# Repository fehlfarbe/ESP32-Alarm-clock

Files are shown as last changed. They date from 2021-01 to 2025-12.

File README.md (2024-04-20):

# ESP32 Alarm clock

This is an ESP32 based alarm clock that plays mp3 files from SD, webstreams or even FM radio.
You can configure multiple alarms and add new songs to your sd card with a simple webinterface.

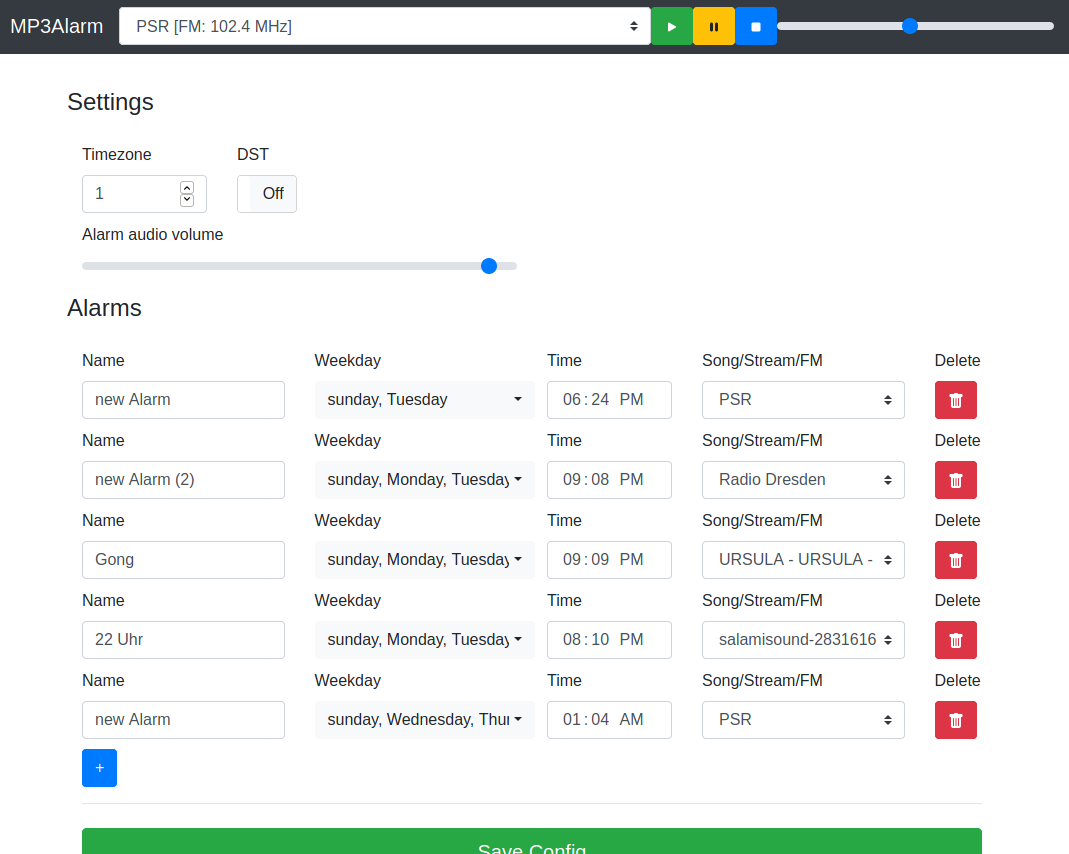
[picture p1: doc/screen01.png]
Screenshot of webinterface


Photos of the current PCB version (without assembled radio antenna connector J10):

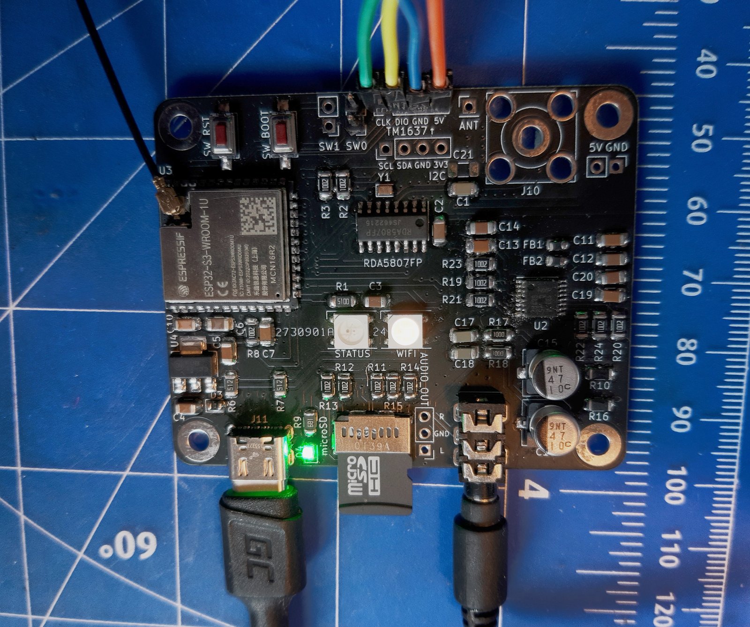
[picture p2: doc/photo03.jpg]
Photo of current PCB top

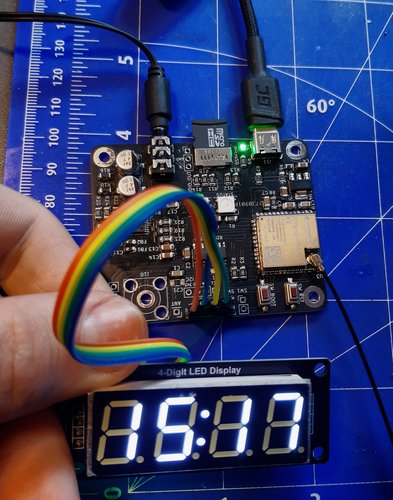
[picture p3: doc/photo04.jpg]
Photo of current PCB with digital clock display


## Features

- designed for ESP32 S3 microcontroller
- plays audio from different sources:
  - MP3/AAC from SD
  - webstreams via WiFi
  - FM radio via [RDA5807FP](https://opendevices.ru/wp-content/uploads/2015/10/RDA5807FP.pdf) module
- output via I2S to a stereo decoder like the [UDA1334A](https://learn.adafruit.com/adafruit-i2s-stereo-decoder-uda1334a).
- see current time on TM1637 4-Digit Digital LED display
- see current WiFi state with WS2812 RGB LED
- simple config and file upload via webinterface

## Hardware

The KiCAD project and gerber files are available at `hardware/pcb/`

### Schematic
schematic

### 2D Plot

#### Front
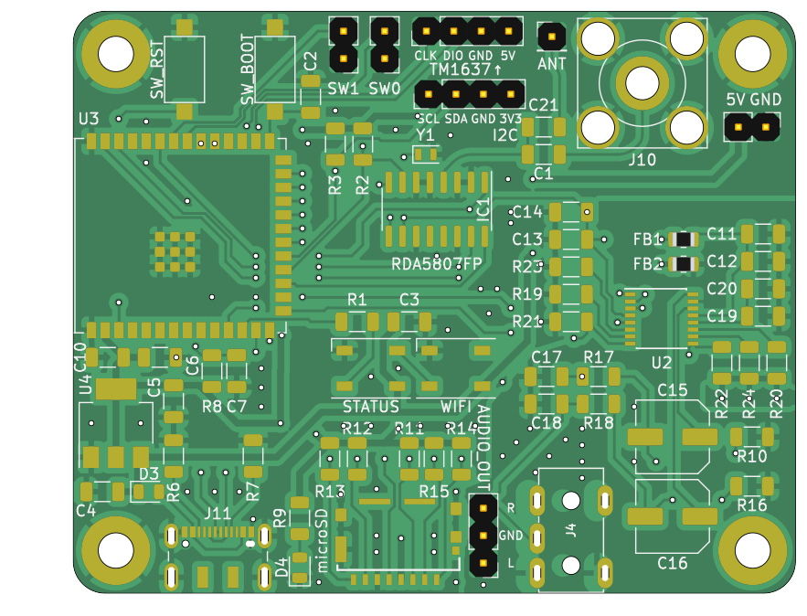
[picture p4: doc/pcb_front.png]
PCB front


#### Back
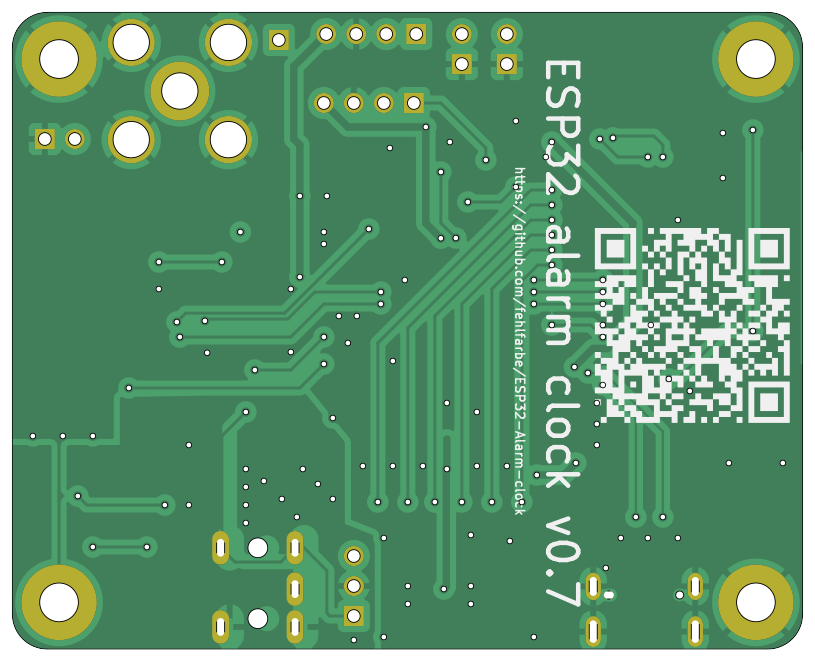
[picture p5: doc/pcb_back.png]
PCB back


### 3D Render

#### Front
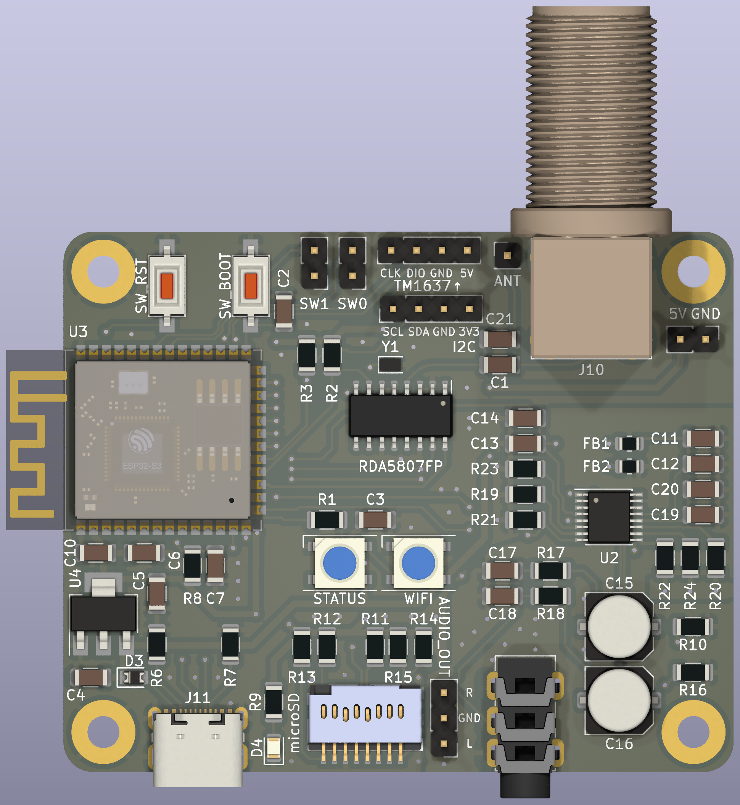
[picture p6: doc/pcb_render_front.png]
PCB front


#### Back
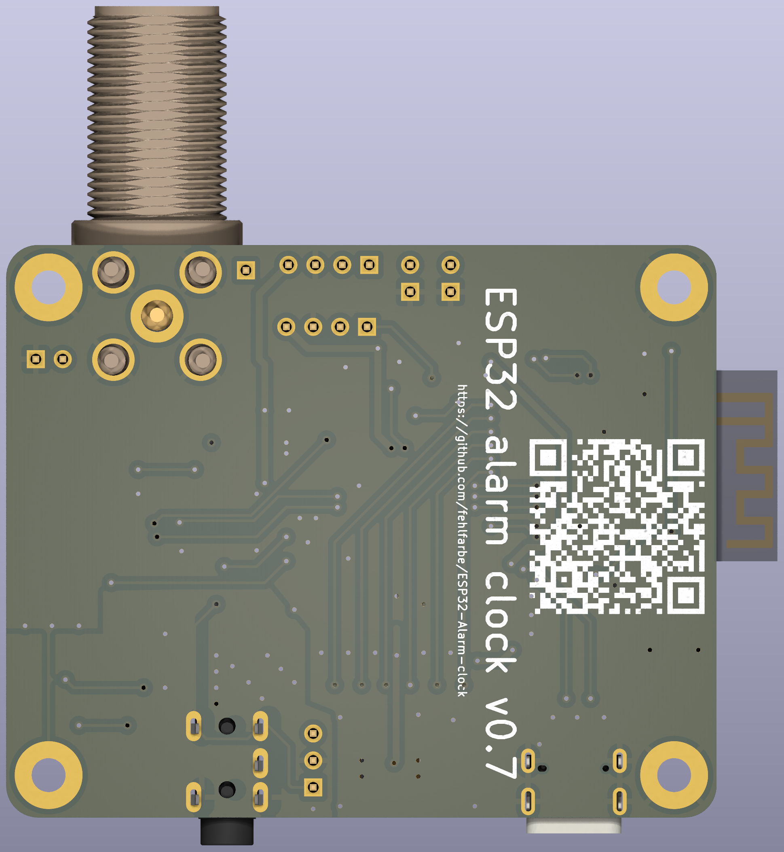
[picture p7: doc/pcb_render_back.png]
PCB back


### BOM

`hardware/pcb/export/BOM.xml`

## LED States

### Status LED

- red 1Hz blinking: An Error has occurred while mounting LITTLEFS
- red 0.5Hz blinking: Cannot mount SD card
- green Everything is fine :)

### WiFi LED

-  blue AccessPoint mode: Connect to the ESP's access point and configure your WiFi
-  red...green WiFi signal strength from bad to good

## Installation

Just clone the project and open it in platformIO. PIO will download all necessary libs. Connect the ESP32 on your USB port an click "Upload" in PIO. After this open a terminal in PIO and run `pio run -t uploadfs` to upload the webinterface to ESP32's flash.
The ESP32 will reboot and opens an accesspoint where you can connect to your WiFi. The clock is synced over the internet via NTP.

## ToDo

- [ ] Add alarm timeout (for webstreams, radio etc.)
- [ ] better web UI based on react
- [x] pictures of full assembled board
- [ ] complete BOM list

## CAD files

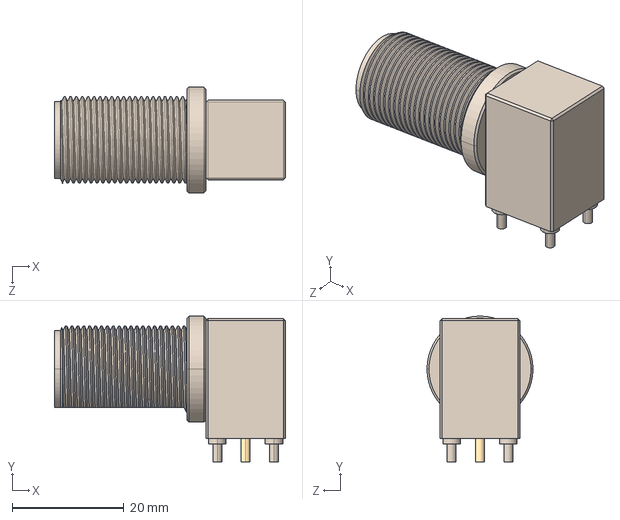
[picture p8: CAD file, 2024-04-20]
hardware/pcb/res/Amphenol RF 172363.STEP
41.4 x 26.1 x 19.0 mm

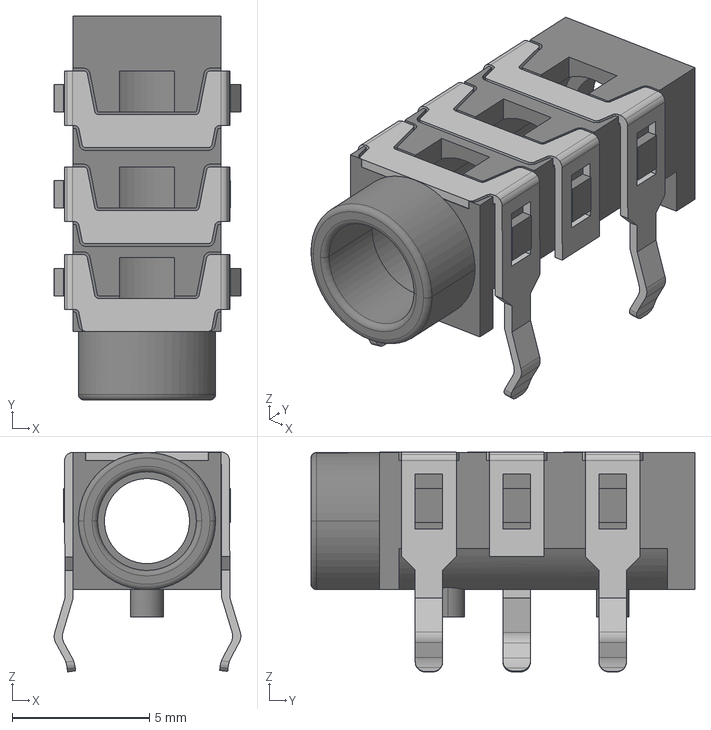
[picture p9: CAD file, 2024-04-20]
hardware/pcb/res/TRS Jack PJ-313.stp
6.81 x 14.0 x 8.02 mm

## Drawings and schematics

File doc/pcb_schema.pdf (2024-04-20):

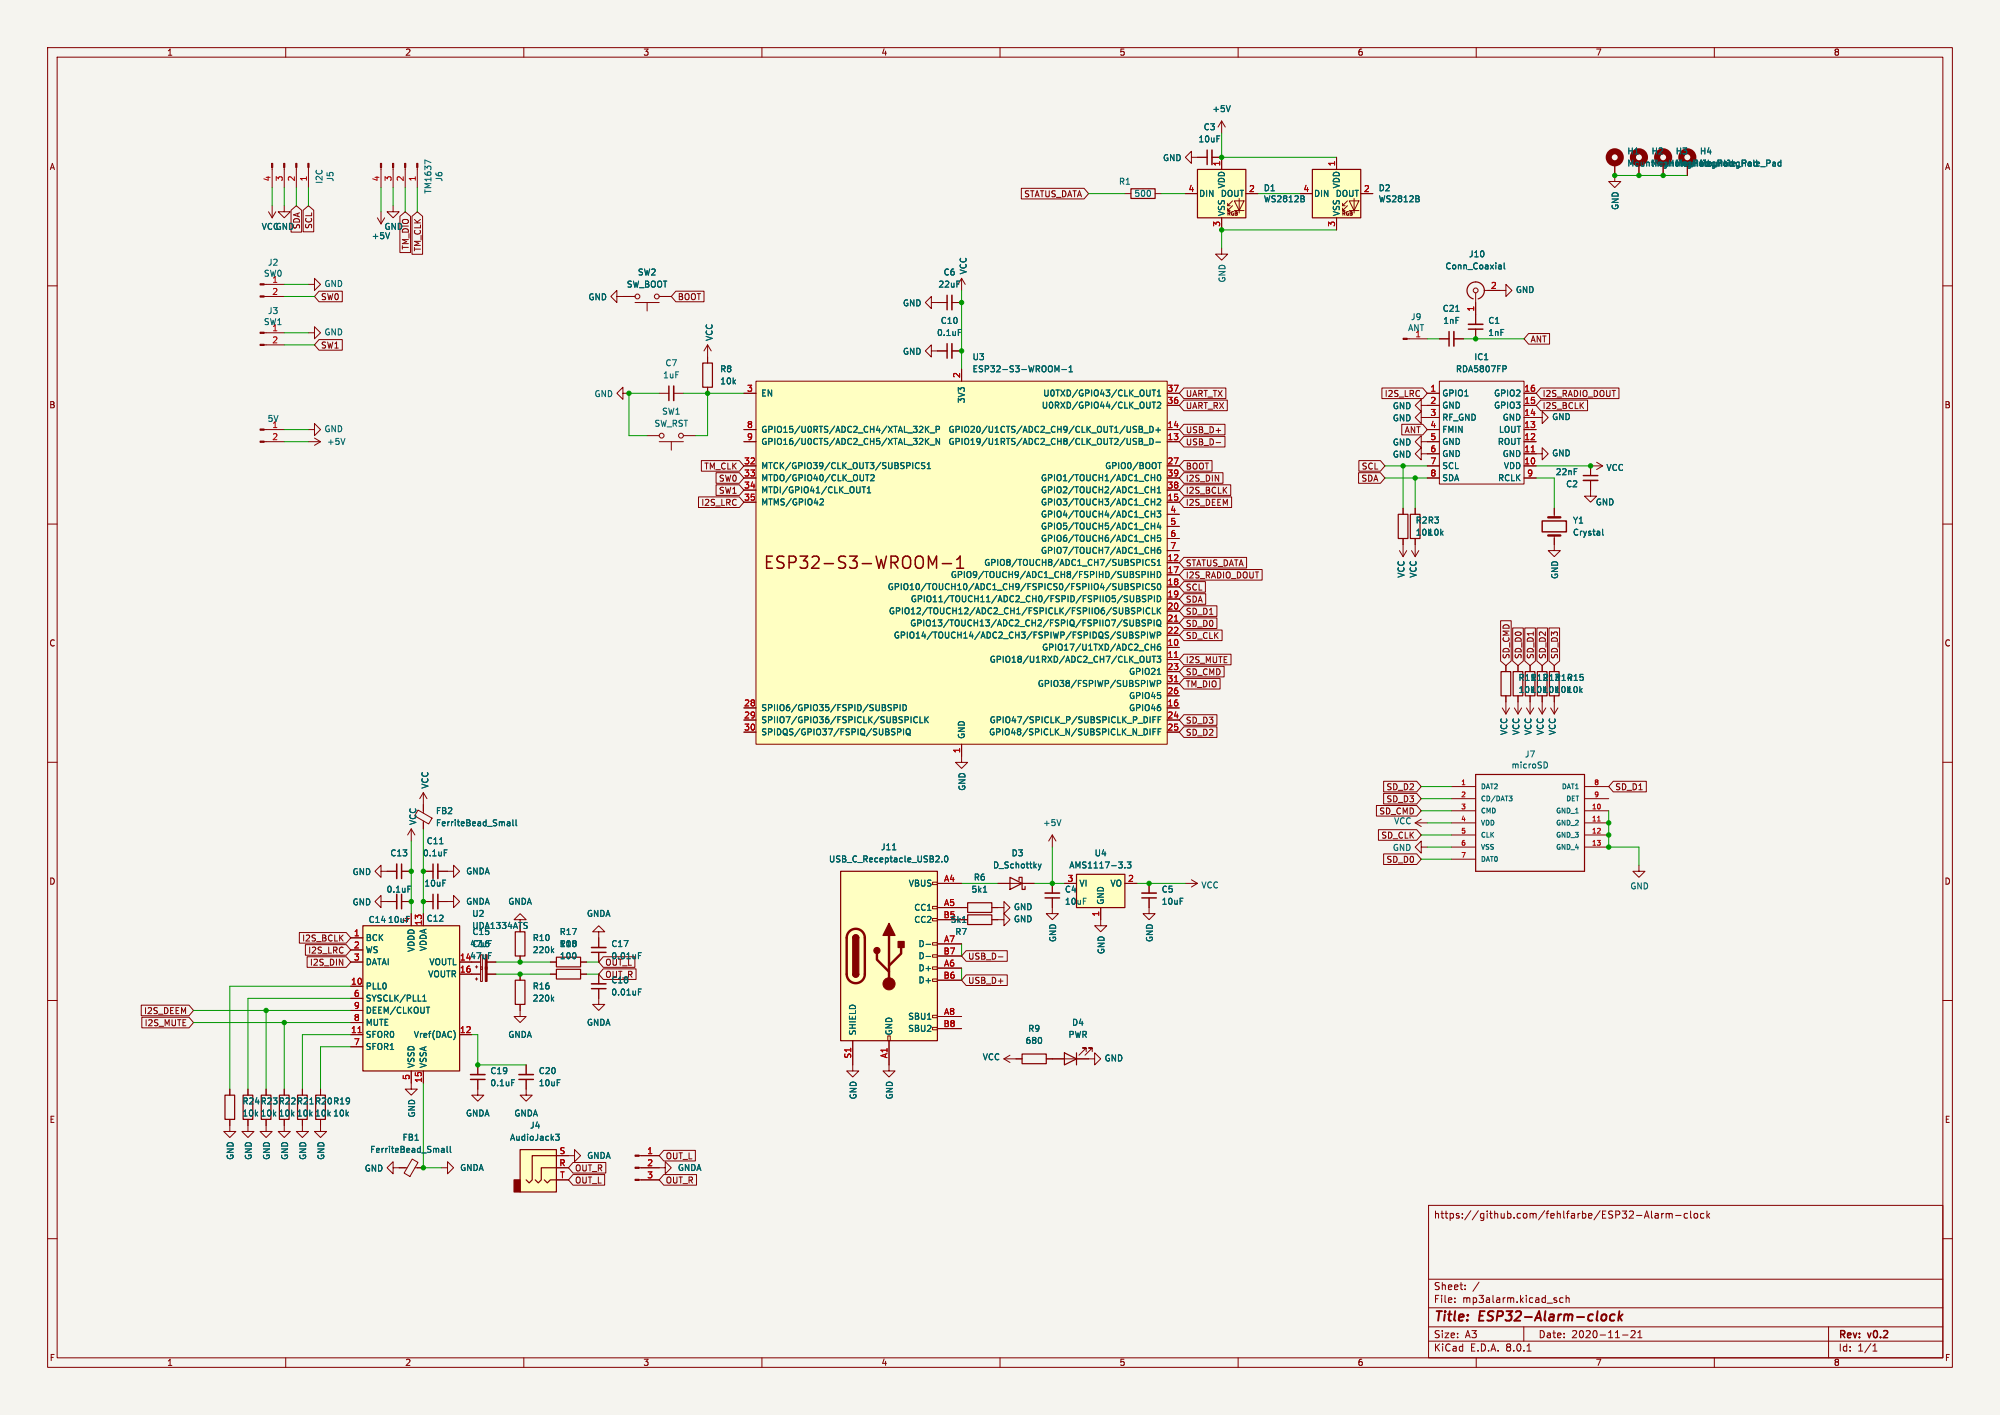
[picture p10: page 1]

3 DIN 4 D1 WS2812B VCC VCC VCC VCC R14

22uF GND GND VCC GND
GND

2 GPIO12/TOUCH12/ADC2_CH1/FSPICLK/FSPIIO6/SUBSPICLK 20 GPIO13/TOUCH13/ADC2_CH2/FSPIQ/FSPIIO7/SUBSPIQ 21 GPIO14/TOUCH14/ADC2_CH3/FSPIWP/FSPIDQS/SUBSPIWP 22 GPIO21 23 GPIO47/SPICLK_P/SUBSPICLK_P_DIFF 24 GPIO48/SPICLK_N/SUBSPICLK_N_DIFF 25 GPIO45 26 GPIO0/BOOT 27 SPIIO6/GPIO35/FSPID/SUBSPID 28 SPIIO7/GPIO36/FSPICLK/SUBSPICLK 29 EN 3 SPIDQS/GPIO37/FSPIQ/SUBSPIQ 30 GPIO38/FSPIWP/SUBSPIWP 31 MTCK/GPIO39/CLK_OUT3/SUBSPICS1 32 MTDO/GPIO40/CLK_OUT2 33 MTDI/GPIO41/CLK_OUT1 34 MTMS/GPIO42 35 U0RXD/GPIO44/CLK_OUT2 36 U0TXD/GPIO43/CLK_OUT1 37 GPIO2/TOUCH2/ADC1_CH1 38 GPIO1/TOUCH1/ADC1_CH0 39 GPIO4/TOUCH4/ADC1_CH3 4 GPIO5/TOUCH5/ADC1_CH4 5 GPIO6/TOUCH6/ADC1_CH5 6 GPIO7/TOUCH7/ADC1_CH6 7 GPIO15/U0RTS/ADC2_CH4/XTAL_32K_P 8 GPIO16/U0CTS/ADC2_CH5/XTAL_32K_N 9 U3ESP32-S3-WROOM-1 VCC C5

File: mp3alarm.kicad_sch Sheet: / https://github.com/fehlfarbe/ESP32-Alarm-clock VCC

2 GPIO12/TOUCH12/ADC2_CH1/FSPICLK/FSPIIO6/SUBSPICLK 20 GPIO13/TOUCH13/ADC2_CH2/FSPIQ/FSPIIO7/SUBSPIQ 21 GPIO14/TOUCH14/ADC2_CH3/FSPIWP/FSPIDQS/SUBSPIWP 22 GPIO21 23 GPIO47/SPICLK_P/SUBSPICLK_P_DIFF 24 GPIO48/SPICLK_N/SUBSPICLK_N_DIFF 25 GPIO45 26 GPIO0/BOOT 27 SPIIO6/GPIO35/FSPID/SUBSPID 28 SPIIO7/GPIO36/FSPICLK/SUBSPICLK 29 EN 3 SPIDQS/GPIO37/FSPIQ/SUBSPIQ 30 GPIO38/FSPIWP/SUBSPIWP 31 MTCK/GPIO39/CLK_OUT3/SUBSPICS1 32 MTDO/GPIO40/CLK_OUT2 33 MTDI/GPIO41/CLK_OUT1 34 MTMS/GPIO42 35 U0RXD/GPIO44/CLK_OUT2 36 U0TXD/GPIO43/CLK_OUT1 37 GPIO2/TOUCH2/ADC1_CH1 38 GPIO1/TOUCH1/ADC1_CH0 39 GPIO4/TOUCH4/ADC1_CH3 4 GPIO5/TOUCH5/ADC1_CH4 5 GPIO6/TOUCH6/ADC1_CH5 6 GPIO7/TOUCH7/ADC1_CH6 7 GPIO15/U0RTS/ADC2_CH4/XTAL_32K_P 8 GPIO16/U0CTS/ADC2_CH5/XTAL_32K_N 9 C5

1 GPIO17/U1TXD/ADC2_CH6 10 GPIO18/U1RXD/ADC2_CH7/CLK_OUT3 11 GPIO8/TOUCH8/ADC1_CH7/SUBSPICS1 12 GPIO19/U1RTS/ADC2_CH8/CLK_OUT2/USB_D- 13 GPIO20/U1CTS/ADC2_CH9/CLK_OUT1/USB_D+ 14 GPIO3/TOUCH3/ADC1_CH2 15 GPIO46 16 GPIO9/TOUCH9/ADC1_CH8/FSPIHD/SUBSPIHD 17 GPIO10/TOUCH10/ADC1_CH9/FSPICS0/FSPIIO4/SUBSPICS0 18 GPIO11/TOUCH11/ADC2_CH0/FSPID/FSPIIO5/SUBSPID 19 3V3

5 SYSCLK/PLL1 6 SFOR1 7 MUTE 8 DEEM/CLKOUT 9 U2 UDA1334ATS C19

5 SYSCLK/PLL1 6 SFOR1 7 MUTE 8 DEEM/CLKOUT 9 C19

Id: 1/1 Title: ESP32-Alarm-clock

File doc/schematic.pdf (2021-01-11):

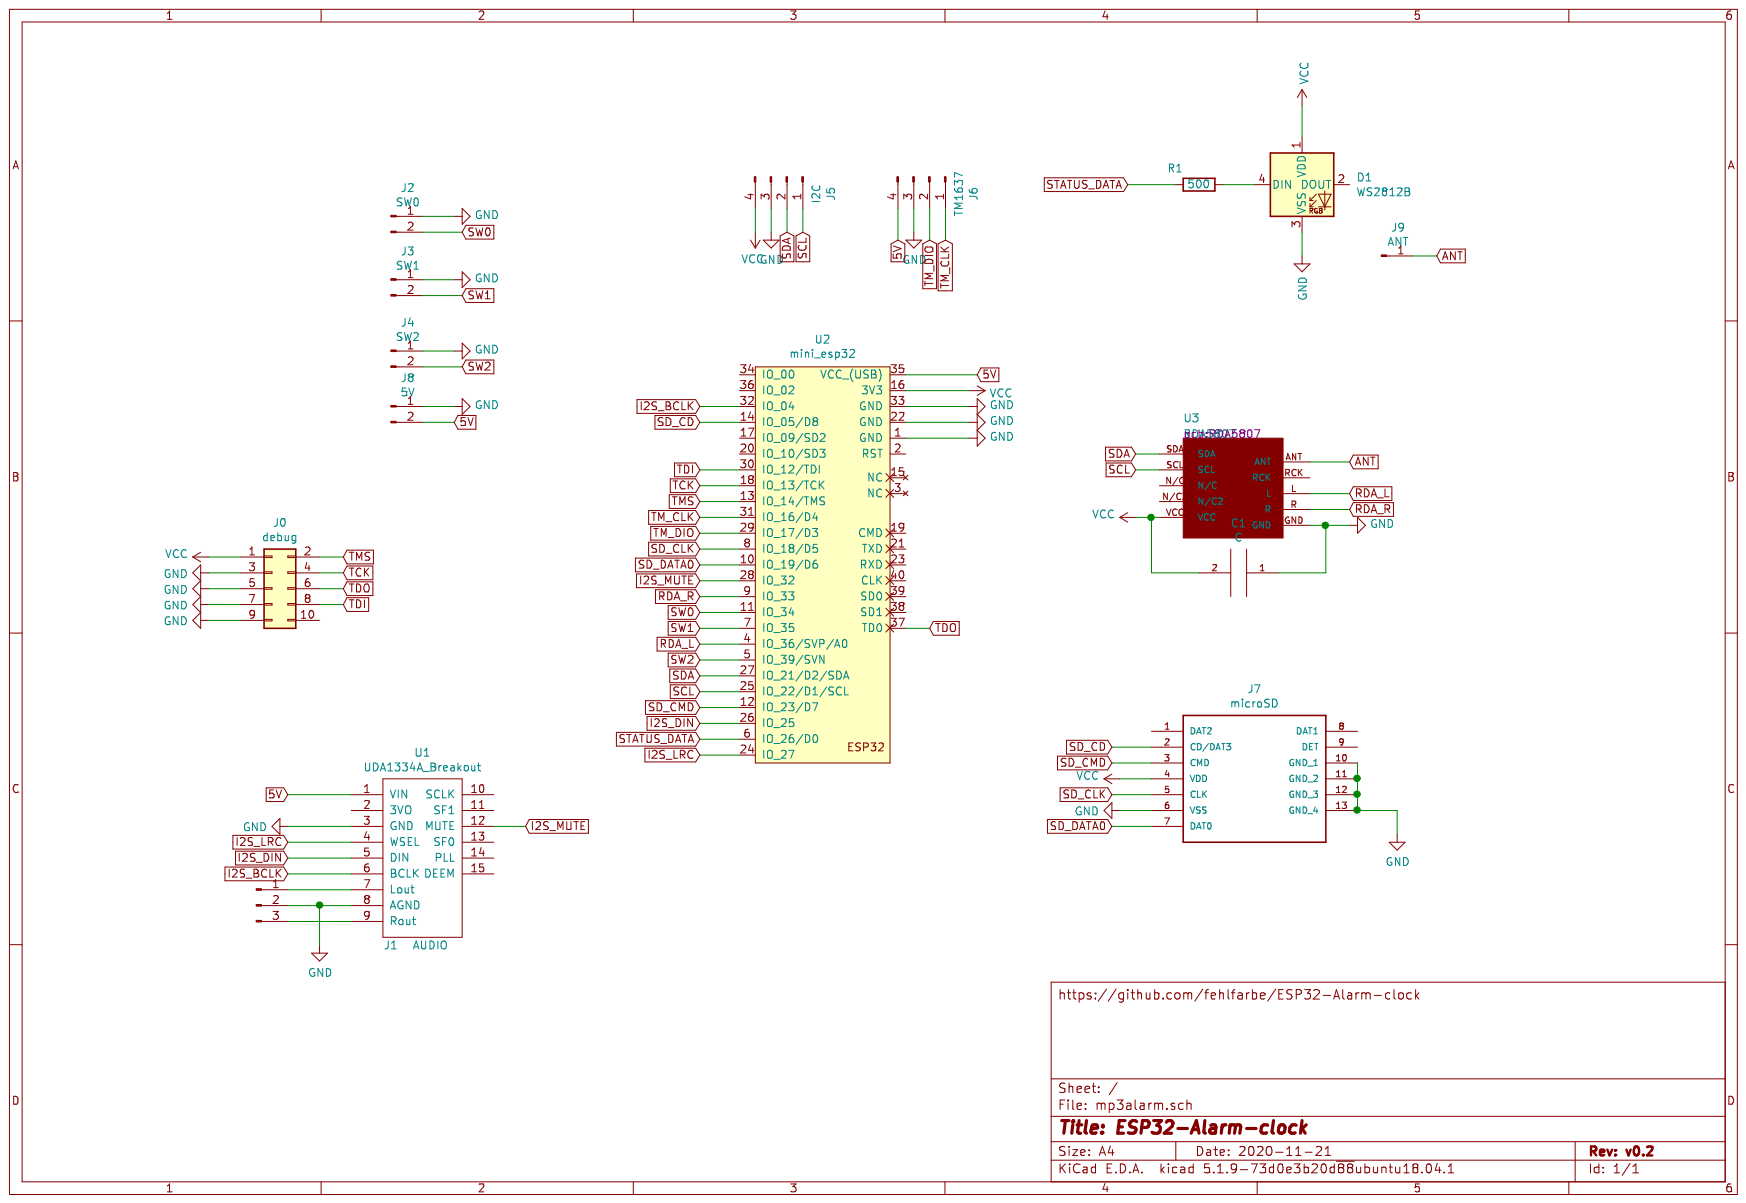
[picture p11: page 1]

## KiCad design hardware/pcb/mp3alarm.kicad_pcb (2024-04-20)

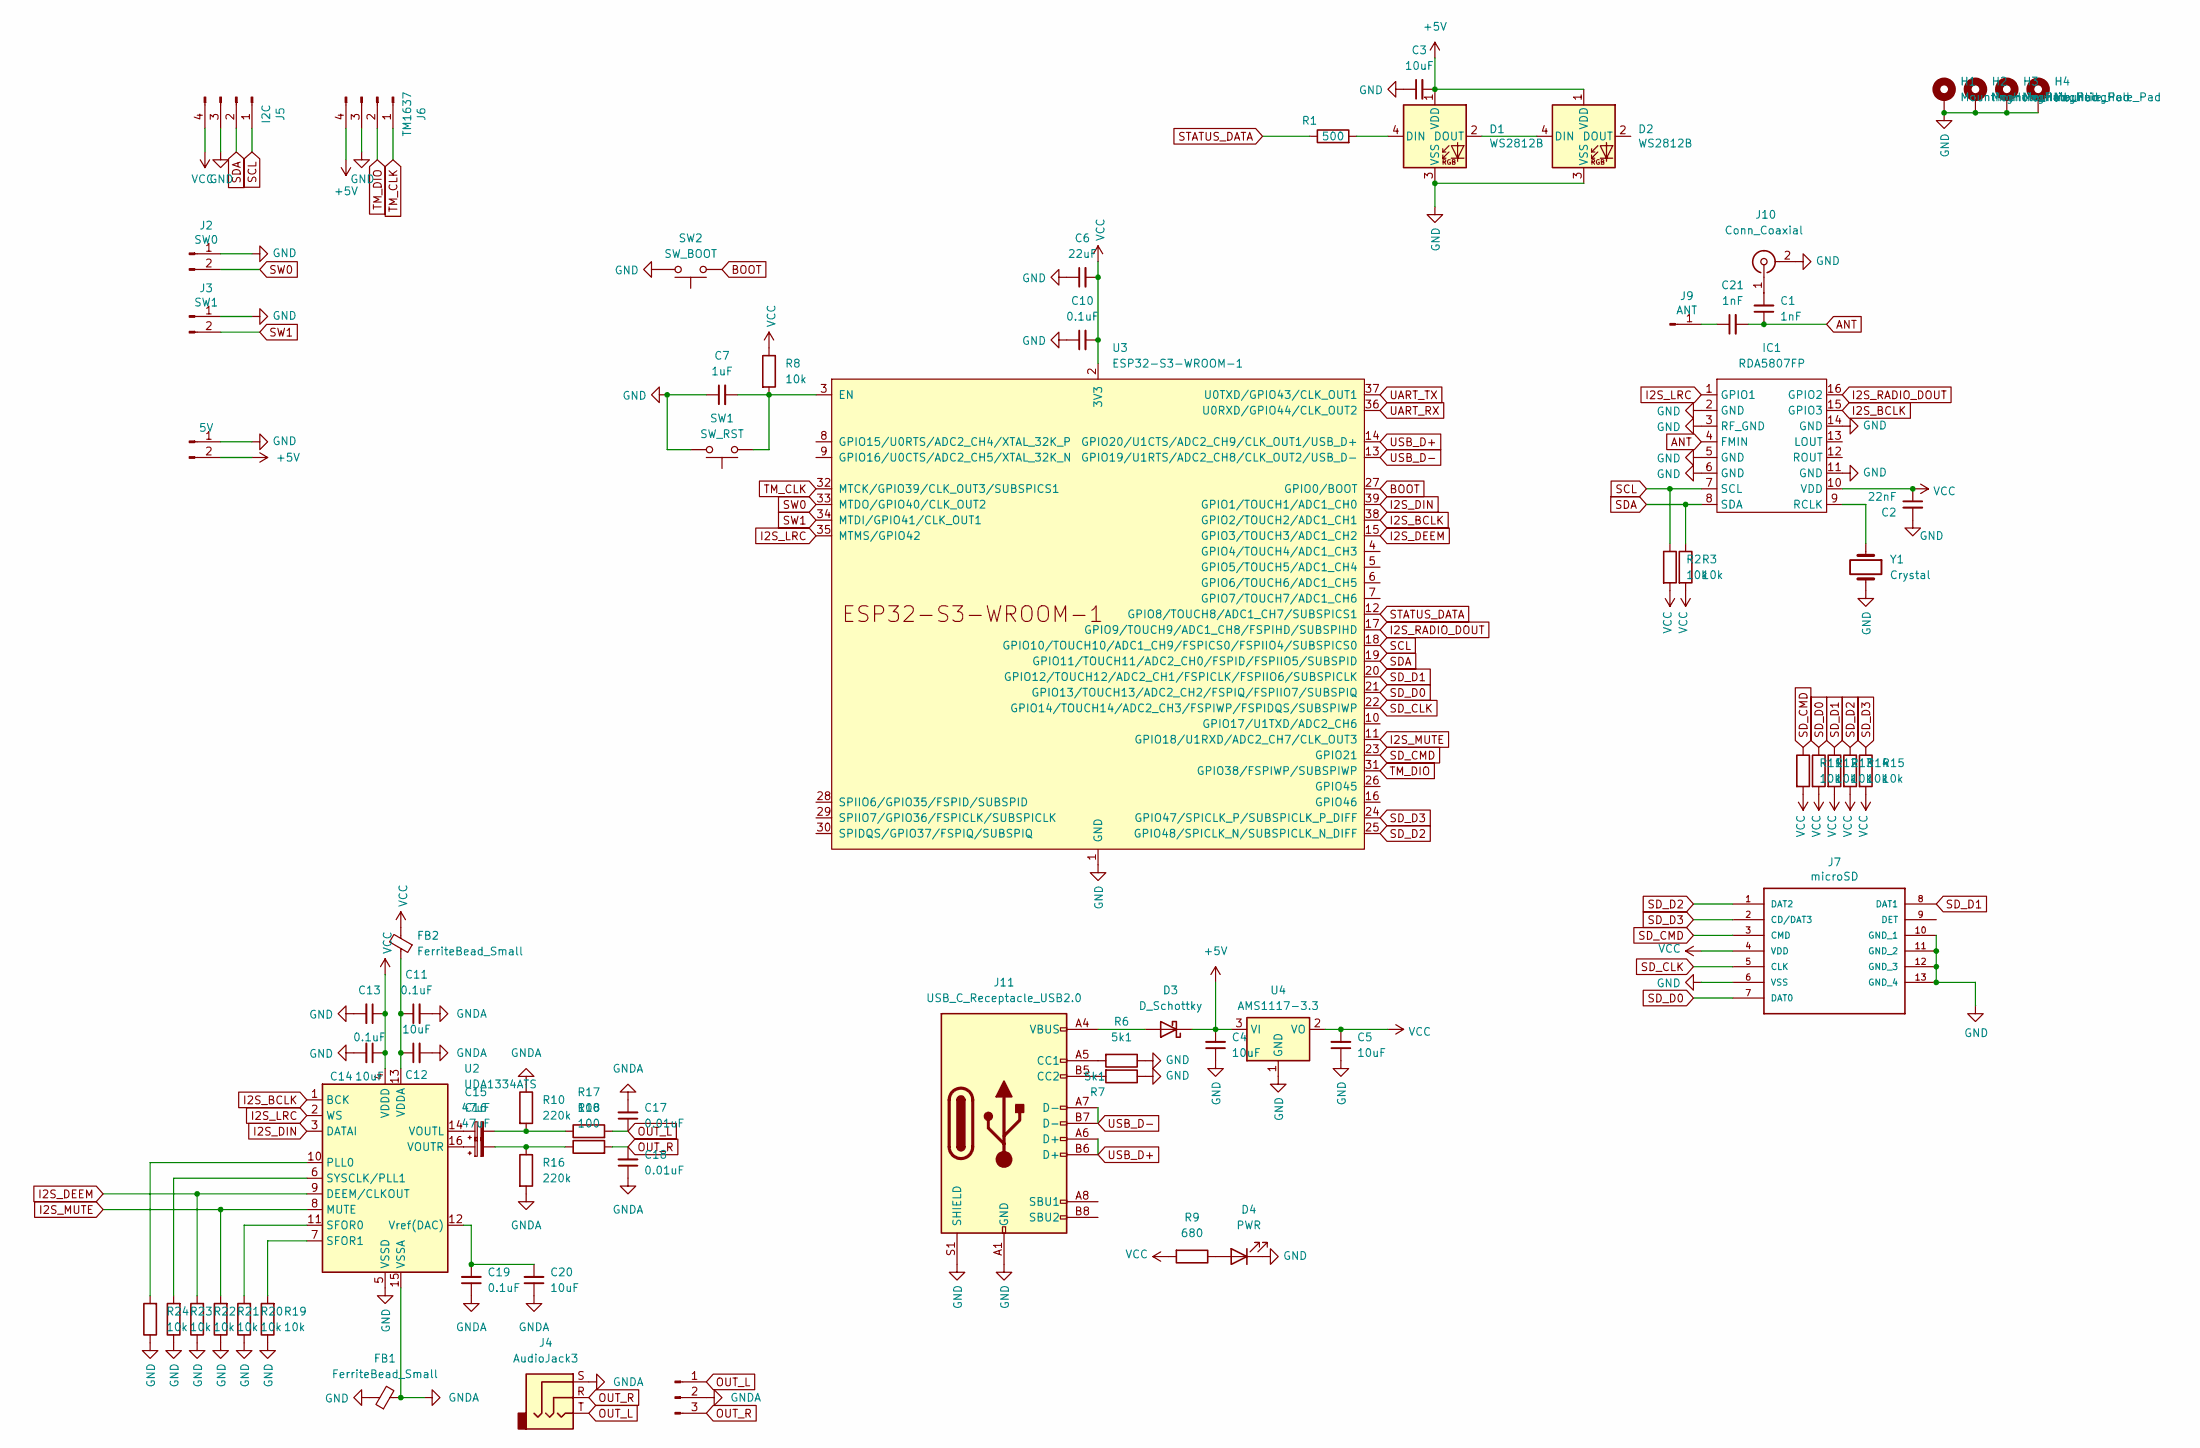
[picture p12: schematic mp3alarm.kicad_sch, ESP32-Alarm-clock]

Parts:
C1, C21: 1nF; C_1206_3216Metric
C2: 22nF; C_1206_3216Metric
C3, C4, C5, C12, C14, C20: 10uF; C_1206_3216Metric
C6: 22uF; C_1206_3216Metric
C7: 1uF; C_1206_3216Metric
C10, C11, C13, C19: 0.1uF; C_1206_3216Metric
C15, C16: 47uF; C_Elec_6.3x5.4
C17, C18: 0.01uF; C_1206_3216Metric
D1, D2: WS2812B; LED_WS2812B_PLCC4_5.0x5.0mm_P3.2mm
D3: D_Schottky; D_0805_2012Metric
D4: PWR; LED_0805_2012Metric
FB1, FB2: FerriteBead_Small; R_0805_2012Metric
H1, H2, H3, H4: MountingHole_Pad; MountingHole_3.2mm_M3_Pad
IC1: RDA5807FP; SOP-16_3.9x9.9mm_P1.27mm
J1: AUDIO; PinHeader_1x03_P2.54mm_Vertical
J2: SW0; PinHeader_1x02_P2.54mm_Vertical
J3: SW1; PinHeader_1x02_P2.54mm_Vertical
J4: AudioJack3; PJ-313
J5: I2C; PinHeader_1x04_P2.54mm_Vertical
J6: TM1637; PinHeader_1x04_P2.54mm_Vertical
J7: microSD; 105162-0001; MOUSER_PART_NUMBER 538-105162-0001
J8: 5V; PinHeader_1x02_P2.54mm_Vertical
J9: ANT; PinHeader_1x01_P2.54mm_Vertical
J10: Conn_Coaxial; F_Sat_Connector
J11: USB_C_Receptacle_USB2.0; USB_C_Receptacle_JAE_DX07S016JA1R1500
R1: 500; R_1206_3216Metric
R2, R3, R8, R11, R12, R13, R14, R15, R19, R20, R21, R22, R23, R24: 10k; R_1206_3216Metric
R6, R7: 5k1; R_1206_3216Metric
R9: 680; R_1206_3216Metric
R10, R16: 220k; R_1206_3216Metric
R17, R18: 100; R_1206_3216Metric
SW1: SW_RST; SW_SPST_CK_RS282G05A3
SW2: SW_BOOT; SW_SPST_CK_RS282G05A3
U2: UDA1334ATS; SSOP-16_4.4x5.2mm_P0.65mm
U3: ESP32-S3-WROOM-1
U4: AMS1117-3.3; SOT-223-3_TabPin2
Y1: Crystal; Crystal_SMD_2012-2Pin_2.0x1.2mm

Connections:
+5V: C3.2, C4.2, D1.1 (VDD), D2.1 (VDD), D3.1 (K), J6.4, J8.2, U4.3 (VI)
ANT: C1.1, C21.2, IC1.4 (FMIN)
BOOT: SW2.1, U3.27 (GPIO0/BOOT)
GND: C2.2, C3.1, C4.1, C5.1, C6.1, C7.1, C10.1, C13.2, C14.2, D1.3 (VSS), D2.3 (VSS), D4.1 (K), FB1.1, H1.1, H2.1, H3.1, H4.1, IC1.2 (GND), IC1.3 (RF_GND), IC1.5 (GND), IC1.6 (GND), IC1.11 (GND), IC1.14 (GND), J2.1, J3.1, J5.3, J6.3, J7.6 (VSS), J7.10 (GND_1), J7.11 (GND_2), J7.12 (GND_3), J7.13 (GND_4), J8.1, J10.2 (Ext), J11.A1 (GND), J11.A12 (GND), J11.B1 (GND), J11.B12 (GND), J11.S1 (SHIELD), R6.1, R7.1, R19.1, R20.1, R21.1, R22.1, R23.1, R24.1, SW1.2, SW2.2, U2.5 (VSSD), U3.1 (GND), U3.40 (GND), U3.41 (GND), U4.1 (GND), Y1.2
GNDA: C11.2, C12.2, C17.2, C18.1, C19.1, C20.1, FB1.2, J1.2, J4.S, R10.1, R16.2, U2.15 (VSSA)
I2S_BCLK: IC1.15 (GPIO3), U2.1 (BCK), U3.38 (GPIO2/TOUCH2/ADC1_CH1)
I2S_DEEM: R22.2, U2.9 (DEEM/CLKOUT), U3.15 (GPIO3/TOUCH3/ADC1_CH2)
I2S_DIN: U2.3 (DATAI), U3.39 (GPIO1/TOUCH1/ADC1_CH0)
I2S_LRC: IC1.1 (GPIO1), U2.2 (WS), U3.35 (MTMS/GPIO42)
I2S_MUTE: R21.2, U2.8 (MUTE), U3.11 (GPIO18/U1RXD/ADC2_CH7/CLK_OUT3)
I2S_RADIO_DOUT: IC1.16 (GPIO2), U3.17 (GPIO9/TOUCH9/ADC1_CH8/FSPIHD/SUBSPIHD)
unnamed: C15.2, R10.2, R17.1
unnamed: C16.2, R16.1, R18.1
unnamed: D1.4 (DIN), R1.2
unnamed: D1.2 (DOUT), D2.4 (DIN)
unnamed: D3.2 (A), J11.A4 (VBUS), J11.A9 (VBUS), J11.B4 (VBUS), J11.B9 (VBUS)
unnamed: D4.2 (A), R9.1
unnamed: IC1.9 (RCLK), Y1.1
unnamed: C21.1, J9.1
unnamed: C1.2, J10.1 (In)
unnamed: J11.A5 (CC1), R6.2
unnamed: J11.B5 (CC2), R7.2
unnamed: R24.2, U2.10 (PLL0)
unnamed: R20.2, U2.11 (SFOR0)
unnamed: R19.2, U2.7 (SFOR1)
unnamed: R23.2, U2.6 (SYSCLK/PLL1)
unnamed: C11.1, C12.1, FB2.1, U2.13 (VDDA)
unnamed: C15.1, U2.14 (VOUTL)
unnamed: C16.1, U2.16 (VOUTR)
unnamed: C19.2, C20.2, U2.12 (Vref(DAC))
unnamed: C7.2, R8.2, SW1.1, U3.3 (EN)
OUT_L: C17.1, J1.1, J4.T, R17.2
OUT_R: C18.2, J1.3, J4.R, R18.2
SCL: IC1.7 (SCL), J5.1, R2.1, U3.18 (GPIO10/TOUCH10/ADC1_CH9/FSPICS0/FSPIIO4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)
SDA: IC1.8 (SDA), J5.2, R3.1, U3.19 (GPIO11/TOUCH11/ADC2_CH0/FSPID/FSPIIO5/S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)
SD_CLK: J7.5 (CLK), U3.22 (GPIO14/TOUCH14/ADC2_CH3/FSPIWP/FSPIDQS/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)
SD_CMD: J7.3 (CMD), R11.1, U3.23 (GPIO21)
SD_D0: J7.7 (DAT0), R12.1, U3.21 (GPIO13/TOUCH13/ADC2_CH2/FSPIQ/FSPIIO7/S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)
SD_D1: J7.8 (DAT1), R13.1, U3.20 (GPIO12/TOUCH12/ADC2_CH1/FSPICLK/FSPIIO6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)
SD_D2: J7.1 (DAT2), R14.1, U3.25 (GPIO48/SPICLK_N/SUBSPICLK_N_DIFF)
SD_D3: J7.2 (CD/DAT3), R15.1, U3.24 (GPIO47/SPICLK_P/SUBSPICLK_P_DIFF)
STATUS_DATA: R1.1, U3.12 (GPIO8/TOUCH8/ADC1_CH7/SUBSPICS1)
SW0: J2.2, U3.33 (MTDO/GPIO40/CLK_OUT2)
SW1: J3.2, U3.34 (MTDI/GPIO41/CLK_OUT1)
TM_CLK: J6.1, U3.32 (MTCK/GPIO39/CLK_OUT3/SUBSPICS1)
TM_DIO: J6.2, U3.31 (GPIO38/FSPIWP/SUBSPIWP)
UART_RX: U3.36 (U0RXD/GPIO44/CLK_OUT2)
UART_TX: U3.37 (U0TXD/GPIO43/CLK_OUT1)
USB_D+: J11.A6 (D+), J11.B6 (D+), U3.14 (GPIO20/U1CTS/ADC2_CH9/CLK_OUT1/USB_D+)
USB_D-: J11.A7 (D-), J11.B7 (D-), U3.13 (GPIO19/U1RTS/ADC2_CH8/CLK_OUT2/USB_D-)
VCC: C2.1, C5.2, C6.2, C10.2, C13.1, C14.1, FB2.2, IC1.10 (VDD), J5.4, J7.4 (VDD), R2.2, R3.2, R8.1, R9.2, R11.2, R12.2, R13.2, R14.2, R15.2, U2.4 (VDDD), U3.2 (3V3), U4.2 (VO)

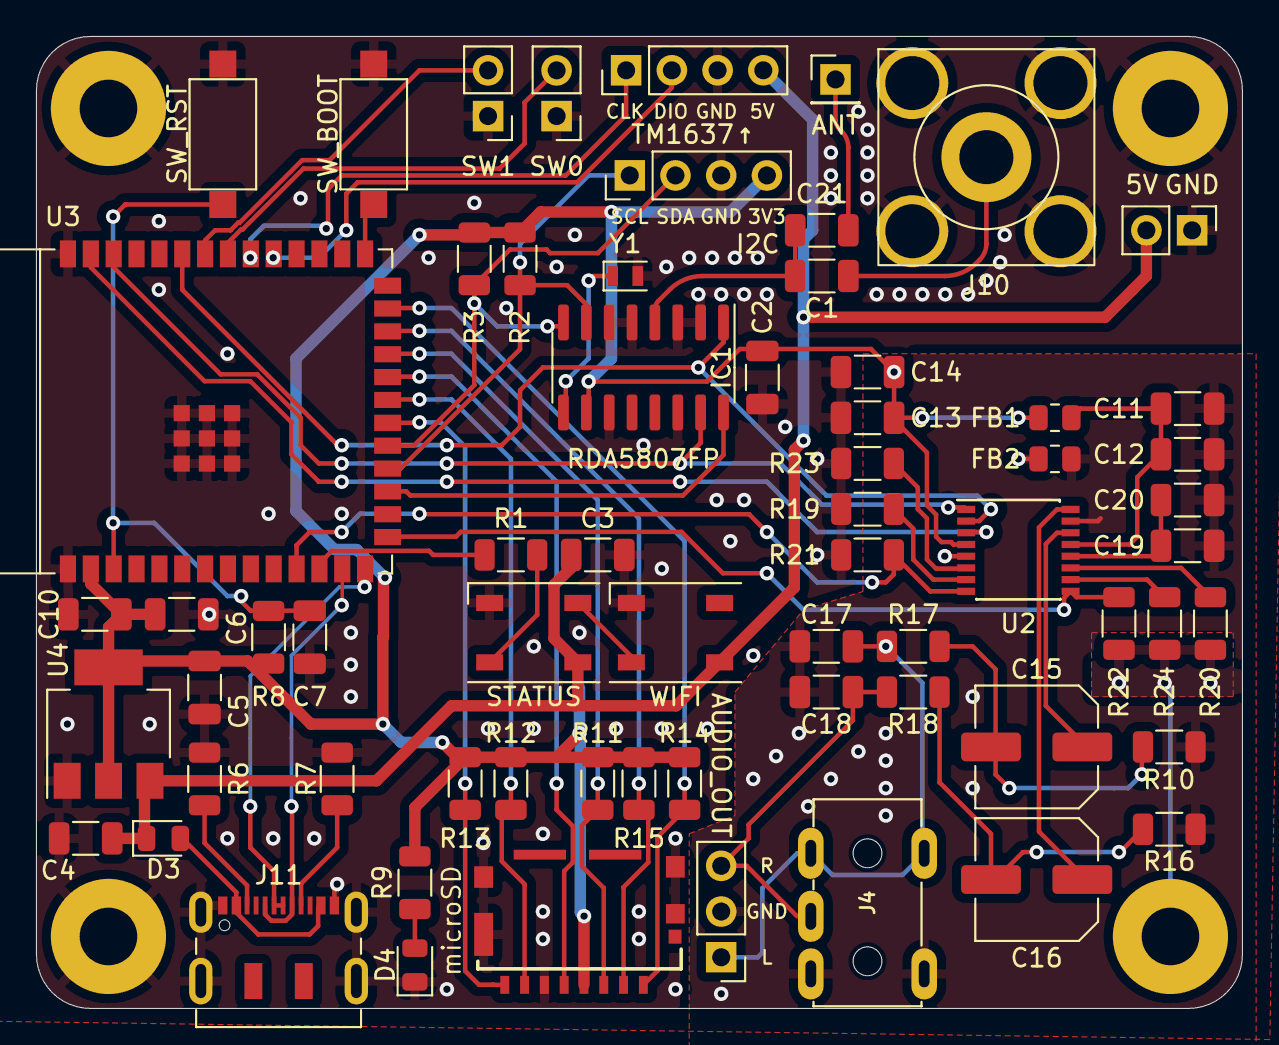
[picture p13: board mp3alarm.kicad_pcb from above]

Board: 2 copper layers, 67.0 x 54.0 mm, 69 parts (0 on the bottom side), 49 nets.

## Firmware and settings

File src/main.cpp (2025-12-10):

#include <Arduino.h>
#include <ArduinoJson.h>
#include <AsyncJson.h>
#include <DNSServer.h>
#include <ESPAsyncWebServer.h>
#include <ESPAsyncWiFiManager.h>
#include <ESPmDNS.h>
#include <FS.h>
#include <FastLED.h>
#include <HTTPClient.h>
#include <Int64String.h>
#include <LittleFS.h>
#include <SD_MMC.h>
#include <SPI.h>
#include <TM1637Display.h>
#include <TimeLib.h>
#include <Update.h>
#include <WiFi.h>
#include <WiFiUdp.h>
#include <time.h>

#define LOG_LOCAL_LEVEL ESP_LOG_VERBOSE
#include <esp_log.h>

#include "Alarm.h"
#include "AudioProvider.h"
#include "Config.h"
#include "MusicStream.h"
#include "utils.h"

// Digital I/O used
#define I2S_DOUT 1
#define I2S_BCLK 2
#define I2S_WS 42
#define I2S_RADIO_OUT 9
#define I2S_MUTE 18
#define I2S_DEEM 3

// SD_MMC
#define SD_MMC_CLK 14
#define SD_MMC_CMD 21
#define SD_MMC_D0 13
#define SD_MMC_D1 12
#define SD_MMC_D2 48
#define SD_MMC_D3 47

#define SW0 40
#define SW1 41
#define SW_WIFI_RESET SW0
#define LED_STATUS 8

// Display and I2C
#define CLK 39
#define DIO 38
#define SCL 10
#define SDA 11

// Global variables
AudioProvider audio;
unsigned long startTime = millis();
const char* TAG = "ESP32Alarm";

// LED
enum WIFI_LED_STATE {
    STATE_INIT = HUE_PINK,
    STATE_WIFI_CONNECTING = HUE_ORANGE,
    STATE_WIFI_AP = HUE_BLUE,
    STATE_WIFI_AP_CONNECTED = HUE_AQUA,
    STATE_WIFI_CONNECTED = HUE_GREEN,
    STATE_WIFI_DISCONNECTED = HUE_RED
};

enum SYSTEM_LED_STATE {
    STATE_NONE,
    STATE_FS_ERR,
    STATE_SD_ERR,
    STATE_SD_NO_SD,
    STATE_TIME_NOT_SYNCED
};

#define LED_MAX_BRIGHTNESS 150
#define LED_STATUS_IDX 0
#define LED_WIFI_IDX 1
CRGB led_status[2];

SYSTEM_LED_STATE ledSystem = SYSTEM_LED_STATE::STATE_NONE;
WIFI_LED_STATE ledWiFi = WIFI_LED_STATE::STATE_INIT;

// config
AlarmClock::Config config;

// data sources
#define fsSongs SD_MMC
#define fsConfig SD_MMC
const String configPath = "/config.json";
const String streamsPath = "/streams.json";
const String songsDir = "/songs/";

// WebServer
AsyncWebServer server(80);
DNSServer dns;
File fsUploadFile;

// WiFi
AsyncWiFiManager wifiManager(&server, &dns);

// Display
TM1637Display display(CLK, DIO);

// parallel task
TaskHandle_t pTask;
TaskHandle_t pLedTask;

// function declarations
void checkAlarmTask(void* parameter);
void ledTask(void* parameter);
void initSDCardStructure(fs::FS& fs);
void updateAlarms();
void nextAlarm();
void printAlarms();
void listDir(fs::FS& fs, const char* dirname, uint8_t levels);
time_t updateNTPTime();
void printTime(struct tm);
bool checkPlayAlarm();
void showDisplay(DisplayState state);
void setWiFiLEDState(WIFI_LED_STATE state);
void setSystemLEDState(SYSTEM_LED_STATE state);
void configModeCallback(AsyncWiFiManager* myWiFiManager);
void WiFiEvent(WiFiEvent_t event);

void handleAPIConfig(AsyncWebServerRequest* request);
void handleAPISongs(AsyncWebServerRequest* request);
void handleAPISongsUpload(AsyncWebServerRequest* request, String filename, size_t index,
    uint8_t* data, size_t len, bool final);
void handleAPISongsUploadResponse(AsyncWebServerRequest* request);
void handleAPIPlayback(AsyncWebServerRequest* request);
void handleAPIState(AsyncWebServerRequest* request);
void handleOTAUpdateForm(AsyncWebServerRequest* request);
void handleOTAUpdateResponse(AsyncWebServerRequest* request);
void handleOTAUpdateUploadFirmware(AsyncWebServerRequest* request, String filename, size_t index,
    uint8_t* data, size_t len, bool final);
void handleOTAUpdateUploadFilesystem(AsyncWebServerRequest* request, String filename, size_t index,
    uint8_t* data, size_t len, bool final);
void handleReboot(AsyncWebServerRequest* request);
void handleCrash(AsyncWebServerRequest* request);
void handleCoredump(AsyncWebServerRequest* request);

// setup
void setup()
{
    // setup pins
    pinMode(SW0, INPUT_PULLUP);
    pinMode(SW1, INPUT_PULLUP);
    pinMode(I2S_MUTE, OUTPUT);
    pinMode(I2S_DEEM, OUTPUT);

    // setup LEDs
    FastLED.addLeds<NEOPIXEL, LED_STATUS>(led_status, 2);
    // setup parallel task
    xTaskCreatePinnedToCore(ledTask, /* Function to implement the task */
        "ledTask", /* Name of the task */
        getArduinoLoopTaskStackSize(), /* Stack size in words */
        NULL, /* Task input parameter */
        1, /* Priority of the task */
        &pLedTask, /* Task handle. */
        0); /* Core where the task should run */

    // setup serial
    Serial.begin(115200);
    // delay(5000);
    // while (!Serial)
    //     ;

    // init audio
    Serial.println("Setup I2S output");
    // AudioLogger::instance().begin(Serial,AudioLogger::Info);
    audio.init(I2S_BCLK, I2S_DOUT, I2S_WS, I2S_RADIO_OUT, SCL, SDA);
    audio.setVolume(config.GetGlobalConfig().audio_volume); // 0...1
    digitalWrite(I2S_MUTE, LOW);
    digitalWrite(I2S_DEEM, HIGH);

    // setup display
    display.clear();
    display.setBrightness(3, true);
    display.showNumberDec(1, true);

    // Initialize LITTLEFS
    Serial.println("Init flash filesystem");
    if (!LittleFS.begin(false, "/littlefs", 10, "littlefs")) {
        showDisplay(DisplayState::FS_ERR);
        Serial.println("An Error has occurred while mounting flash");
        ledSystem = SYSTEM_LED_STATE::STATE_FS_ERR;
        while (true)
            ;
    }

    listDir(LittleFS, "/", 5);

    // Initialize SD
    SD_MMC.setPins(SD_MMC_CLK, SD_MMC_CMD, SD_MMC_D0, SD_MMC_D1, SD_MMC_D2, SD_MMC_D3);
    while (!SD_MMC.begin("/sdcad", false, false, 20000)) {
        showDisplay(DisplayState::SD_ERR);
        ledSystem = SYSTEM_LED_STATE::STATE_SD_ERR;
        Serial.println("Card Mount Failed");
        while (true)
            ;
    }

    uint8_t cardType = SD_MMC.cardType();
    if (cardType == CARD_NONE) {
        Serial.println("No SD card attached");
        showDisplay(DisplayState::SD_ERR_NO_SD);
        ledSystem = SYSTEM_LED_STATE::STATE_SD_NO_SD;
        while (true)
            ;
    }

    // init SD card (create needed files)
    initSDCardStructure(SD_MMC);
    Serial.println("Files on SD:");
    listDir(SD_MMC, "/", 5);

    // load config
    config.LoadFromPath(fsConfig, configPath);
    audio.setVolume(config.GetGlobalConfig().audio_volume);

    // connect WiFi
    showDisplay(DisplayState::WIFI_CONNECT);
    WiFi.setAutoReconnect(true);
    WiFi.onEvent(WiFiEvent);
    // setup WiFI manager
    // wifiManager.setConnectTimeout(10);
    // wifiManager.setConfigPortalTimeout(0);
    // wifiManager.setAPCallback(configModeCallback);
    // connect to WiFi
    if (digitalRead(SW1) == LOW) {
        Serial.println("Starting AP...");
        config.GetGlobalConfig().isStaticIPEnabled = false; // disable static ip settings
        wifiManager.setTryConnectDuringConfigPortal(false); // don't connect while config portal is forced active
        if(!wifiManager.startConfigPortal(config.GetGlobalConfig().hostname.c_str())) {
            Serial.println("Cannot start config portal");
        };
    } else {
        // setup static ip if it's set in config and SW_WIFI_RESET is not pressed
        if (config.GetGlobalConfig().isStaticIPEnabled) {
            Serial.printf("Found static IP config, set IP to %s\n",
                config.GetGlobalConfig().local.toString().c_str());
            wifiManager.setSTAStaticIPConfig(config.GetGlobalConfig().local,
                config.GetGlobalConfig().gateway, config.GetGlobalConfig().subnet,
                config.GetGlobalConfig().primaryDNS, config.GetGlobalConfig().secondaryDNS);
        }
        if (!wifiManager.autoConnect()) {
            Serial.println("failed to connect, we should reset as see if it connects");
        }
    }
    Serial.println("WiFi connected!");

    // setup mDNS
    if (!MDNS.begin(config.GetGlobalConfig().hostname.c_str())) {
        Serial.println("Error setting up MDNS responder!");
    } else {
        Serial.printf("mDNS responder started with hostname %s.local\n",
            config.GetGlobalConfig().hostname.c_str());
    }

    // show IP
    Serial.println(WiFi.localIP().toString());

    // sync time
    showDisplay(DisplayState::SYNC);
    setSyncProvider(updateNTPTime);

    // print current time
    struct tm timeinfo;
    if (getLocalTime(&timeinfo)) {
        Serial.printf("Current time: ");
        printTime(timeinfo);
        Serial.println();
    }

    // update alarms
    updateAlarms();

    // HTTP Server
    server.begin();
    server.serveStatic("/", LittleFS, "/www/");
    server.on("/api/config", handleAPIConfig);
    // server.on("/api/config/update", HTTP_POST, handleAPIConfigUpdate);
    server.on("/api/state", handleAPIState);
    server.on("/api/songs", handleAPISongs);
    server.on("/api/songs/update", HTTP_POST, handleAPISongs);
    server.on( "/upload", HTTP_POST,handleAPISongsUploadResponse, handleAPISongsUpload);
    server.on("/api/playback", handleAPIPlayback);

    // Simple Firmware Update
    server.on("/update", HTTP_GET, handleOTAUpdateForm);
    server.on(
        "/update_firmware", HTTP_POST, handleOTAUpdateResponse, handleOTAUpdateUploadFirmware);
    server.on(
        "/update_filesystem", HTTP_POST, handleOTAUpdateResponse, handleOTAUpdateUploadFilesystem);
    server.on("/reboot", HTTP_GET, handleReboot);
    server.on("/coredump", HTTP_GET, handleCoredump);

    // setup parallel task
    xTaskCreatePinnedToCore(checkAlarmTask, /* Function to implement the task */
        "checkAlarmTask", /* Name of the task */
        getArduinoLoopTaskStackSize(), /* Stack size in words */
        NULL, /* Task input parameter */
        1, /* Priority of the task */
        &pTask, /* Task handle. */
        0); /* Core where the task should run */
}

void loop()
{
    audio.loop();

    // if(millis() > 10000 && !audio.isPlaying()){
    //     Serial.println("Playing...");
    //     audio.playUrl("http://stream.srg-ssr.ch/m/rsj/mp3_128");
    //     // audio.playFile(fsSongs, "/songs/URSULA - URSULA - 11 Auf der anderen Seite.mp3");
    //     // audio.playRadio(10240);
    // }
    // digitalWrite(LED_BUILTIN, audio.isPlaying());
}

void checkAlarmTask(void* parameter)
{
    auto lastRSSI = millis();
    while (true) {
        // check for alarm and play
        checkPlayAlarm();
        // update display time
        showDisplay(DisplayState::TIME);

        // check buttons
        if (digitalRead(SW1) == LOW) {
            Serial.printf("Button SW1 pressed, stopping music.\n");
            audio.pause();
        }

        // Serial.printf("Free heap %d\n", ESP.getFreeHeap());
        // Serial.printf("Free stack %d\n", uxTaskGetStackHighWaterMark(NULL));
        if (millis() - lastRSSI > 5000) {
            // print current time
            struct tm timeinfo;
            if (getLocalTime(&timeinfo)) {
                printTime(timeinfo);
            }
            Serial.printf(
                ", uptime %ds WiFi [%d]: %s IP: %s, RSSI %d, heap %d, stack %d next alarm: %s\n",
                (millis() - startTime) / 1000, WiFi.isConnected(), WiFi.SSID().c_str(),
                WiFi.localIP().toString().c_str(), WiFi.RSSI(), ESP.getFreeHeap(),
                uxTaskGetStackHighWaterMark(NULL), config.GetNextAlarmTime().toString().c_str());
            lastRSSI = millis();
        }

        delay(100);
    }
    Serial.println("Exit task...");
}

void ledTask(void* parameter)
{
    while (true) {
        setSystemLEDState(ledSystem);
        setWiFiLEDState(ledWiFi);
        FastLED.show();
        delay(100);
    }
}

/**************************************
 *
 * initialized sd card file structure
 *
 * @param fs FileSystem (LITTLEFS, SPIFFS, SD; ...)
 *************************************/
void initSDCardStructure(fs::FS& fs)
{
    if (!fs.exists(configPath)) {
        Serial.println("Config file does not exist! Save default values to file");
        config.Save(fsConfig, configPath);
    }
    if (!fs.exists(streamsPath)) {
        Serial.println("Streams file does not exist! Creating empty file.");
        File streams = fs.open(streamsPath, FILE_WRITE);
        streams.println("[]");
        streams.close();
    }
    if (!fs.exists(songsDir)) {
        Serial.println("Songs directory does not exist! Creating empty directory.");
        fs.mkdir(songsDir);
    }
}

/**************************************
 *
 * sort and update alarms
 *
 *************************************/
void updateAlarms()
{
    // sort alarms by date
    config.SortAlarmTimes();
    Serial.println("Alarms after sort:");
    printAlarms();
    Serial.println();
    // select next alarm
    nextAlarm();
}
/**************************************
 *
 * selects next alarm, based on current time
 *
 *************************************/
void nextAlarm()
{
    // select next alarm
    struct tm timeinfo;
    if (getLocalTime(&timeinfo)) {
        config.SelectNextAlarmTime(timeinfo);
        Serial.println("Current time is:");
        printTime(timeinfo);
        Serial.println();
        Serial.println("Next Alarm is " + config.GetNextAlarmTime().toString());
    }
}

/**************************************
 *
 * check and play alarm, select next one
 *
 *************************************/
bool checkPlayAlarm()
{
    struct tm timeinfo;
    if (!getLocalTime(&timeinfo)) {
        Serial.println("Cannot get local time");
        ledSystem = SYSTEM_LED_STATE::STATE_TIME_NOT_SYNCED;
        return false;
    }
    ledSystem = SYSTEM_LED_STATE::STATE_NONE;

    // check if timer is reached and play file
    auto& nextAlarm = config.GetNextAlarmTime();
    if (nextAlarm < timeinfo && nextAlarm.differenceSec(timeinfo) < 10) {
        Serial.println("Playing Alarm " + nextAlarm.toString());

        // stop current playback and set audio volume
        audio.stop();
        audio.setVolume(nextAlarm.getVolume());

        auto stream = nextAlarm.getStream();
        Serial.printf("Playing %s of type %s from %s with volume %.2f\n",
            nextAlarm.getName().c_str(),
            AlarmClock::MusicStream::typeToString(stream.getType()).c_str(),
            stream.getURL().c_str(), nextAlarm.getVolume());

        switch (stream.getType()) {
        case AlarmClock::MusicType::FILESYSTEM:
            audio.playFile(fsSongs, stream.getURL());
            break;
        case AlarmClock::MusicType::STREAM:
            audio.playUrl(stream.getURL());
            break;
        case AlarmClock::MusicType::FM:
            audio.playRadio(stream.getFMFrequency());
            break;
        default:
            break;
        }

        // select next alarm
        config.IncrementNextAlarmTime();
        Serial.println("Next Alarm is " + config.GetNextAlarmTime().toString());
        return true;
    }

    return false;
}

/**
 * @brief Updates TM1637 display
 *
 * @param state
 */
void showDisplay(DisplayState state)
{
    struct tm timeinfo;
    const uint8_t sync[] = {
        SEG_A | SEG_F | SEG_G | SEG_C | SEG_D, // S
        SEG_F | SEG_G | SEG_B | SEG_C, // Y
        SEG_E | SEG_G | SEG_C, // n
        SEG_E | SEG_G | SEG_D // c
    };
    const uint8_t conn[] = {
        SEG_E | SEG_G | SEG_D, // c
        SEG_E | SEG_G | SEG_D | SEG_C, // o
        SEG_E | SEG_G | SEG_C, // n
        SEG_E | SEG_G | SEG_C // n
    };
    const uint8_t sd_err[] = { SEG_A | SEG_F | SEG_G | SEG_C | SEG_D, // S
        SEG_E | SEG_G | SEG_D | SEG_C | SEG_B, // d
        0, 0 };
    const uint8_t sd_err_no_sd[] = { SEG_E | SEG_G | SEG_C, // n
        SEG_E | SEG_G | SEG_D | SEG_C, // o
        SEG_A | SEG_F | SEG_G | SEG_C | SEG_D, // S
        SEG_E | SEG_G | SEG_D | SEG_C | SEG_B, // d
        0, 0 };
    const uint8_t fs_err[] = { SEG_E | SEG_G | SEG_C, // n
        SEG_E | SEG_G | SEG_D | SEG_C, // o
        SEG_A | SEG_F | SEG_G | SEG_B, // F
        SEG_A | SEG_F | SEG_G | SEG_C | SEG_D, // S
        0, 0 };
    const uint8_t ap[] = { SEG_A | SEG_F | SEG_B | SEG_B | SEG_E | SEG_C, // A
        SEG_A | SEG_F | SEG_G | SEG_B | SEG_E, // P
        0, 0 };

    switch (state) {
    case DisplayState::WIFI_CONNECT:
        display.setSegments(conn);
        break;
    case DisplayState::WIFI_CONNECTED:
        break;
    case DisplayState::WIFI_PORTAL:
        display.setSegments(ap);
        break;
    case DisplayState::SYNC:
        display.setSegments(sync);
        break;
    case DisplayState::TIME:
        if (!getLocalTime(&timeinfo, 1000)) {
            display.showNumberDec(0, true);
        } else {
            display.showNumberDecEx(timeinfo.tm_hour * 100 + timeinfo.tm_min, 0b01000000, true);
        }
        break;
    case DisplayState::SD_ERR:
        display.setSegments(sd_err);
        break;
    case DisplayState::SD_ERR_NO_SD:
        display.setSegments(sd_err_no_sd);
        break;
    case DisplayState::FS_ERR:
        display.setSegments(fs_err);
        break;
    default:
        break;
    }
}

/**************************************
 *
 * Set LED state
 *
 *************************************/
void setWiFiLEDState(WIFI_LED_STATE state)
{
    auto now = millis();
    uint8_t v = LED_MAX_BRIGHTNESS;
    switch (state) {
    case WIFI_LED_STATE::STATE_INIT:
        v = 0;
        break;
    case WIFI_LED_STATE::STATE_WIFI_CONNECTING:
        v *= (now % 2000) / 2000.;
        break;
    default:
        break;
    }

    led_status[LED_WIFI_IDX] = CHSV(state, 255, v);

    if (WiFi.isConnected()) {
        // show wifi strength
        auto rssi = WiFi.RSSI();
        auto rssiColor = 0;
        if (rssi != 0) {
            rssiColor = map(abs(rssi), 50, 90, 96, 0);
        }
        // Serial.printf("RSSI %d\n", rssi);
        led_status[LED_WIFI_IDX] = CHSV(rssiColor, 255, 70);
    }
}

void setSystemLEDState(SYSTEM_LED_STATE state)
{
    auto now = millis();
    switch (state) {
    case SYSTEM_LED_STATE::STATE_SD_ERR:
        // flash with 1 Hz
        led_status[LED_STATUS_IDX] = CHSV(HUE_RED, 255, now % 1000 < 500 ? LED_MAX_BRIGHTNESS : 0);
        break;
    case SYSTEM_LED_STATE::STATE_SD_NO_SD:
        // flash with 0.5 Hz
        led_status[LED_STATUS_IDX] = CHSV(HUE_RED, 255, now % 2000 < 1000 ? LED_MAX_BRIGHTNESS : 0);
        break;
        break;
    case SYSTEM_LED_STATE::STATE_FS_ERR:
        led_status[LED_STATUS_IDX] = CHSV(HUE_ORANGE, 255, LED_MAX_BRIGHTNESS);
        break;
    case SYSTEM_LED_STATE::STATE_TIME_NOT_SYNCED:
        led_status[LED_STATUS_IDX] = CHSV(HUE_YELLOW, 255, LED_MAX_BRIGHTNESS);
        break;
    default:
        led_status[LED_STATUS_IDX] = CHSV(0, 0, 0);
        break;
    }
}
/**************************************
 *
 * Print all falarms for debug reasons :)
 *
 *************************************/
void printAlarms()
{
    for (size_t i = 0; i < config.getAalarmTimes().size(); i++) {
        auto a = config.getAalarmTimes()[i];
        Serial.printf("[%02d] Alarm %s\n", i, a.toString().c_str());
    }
}
/**************************************
 *
 * Print all files on LITTLEFS for debug reasons :)
 *
 *************************************/
void listDir(fs::FS& fs, const char* dirname, uint8_t levels)
{
    ESP_LOGI(TAG, "Listing directory: %s\n", dirname);

    File root = fs.open(dirname, FILE_READ, false);
    if (!root) {
        ESP_LOGI(TAG, "Failed to open directory");
        return;
    }
    if (!root.isDirectory()) {
        ESP_LOGI(TAG, "Not a directory");
        return;
    }

    File file = root.openNextFile();
    while (file) {
        if (file.isDirectory()) {
            ESP_LOGI(TAG, "  DIR : %s", file.name());
            if (levels) {
                listDir(
                    fs, (String(dirname) + String("/") + String(file.name())).c_str(), levels - 1);
            }
        } else {
            ESP_LOGI(TAG, "  FILE: %s SIZE %d", file.name(), file.size());
        }
        file = root.openNextFile();
    }
}

void configModeCallback(AsyncWiFiManager* myWiFiManager)
{
    // setLWiFiLEDState(LED_STATE::STATE_WIFI_AP);
    Serial.println("Entered config mode");
    Serial.println(WiFi.softAPIP());
    Serial.println(myWiFiManager->getConfigPortalSSID());
    ledWiFi = WIFI_LED_STATE::STATE_WIFI_AP;
}

/**
 * @brief handles WiFi events and auto reconnects
 *
 */
void WiFiEvent(WiFiEvent_t event)
{
    switch (event) {
    case ARDUINO_EVENT_WIFI_AP_START:
        ESP_LOGI(TAG, "AP Started");
        ledWiFi = WIFI_LED_STATE::STATE_WIFI_AP;
        break;
    case ARDUINO_EVENT_WIFI_AP_STACONNECTED:
        ESP_LOGI(TAG, "AP user connected");
        ledWiFi = WIFI_LED_STATE::STATE_WIFI_AP_CONNECTED;
        break;
    case ARDUINO_EVENT_WIFI_AP_STOP:
        ESP_LOGI(TAG, "AP Stopped");
        ledWiFi = WIFI_LED_STATE::STATE_INIT;
        break;
    case ARDUINO_EVENT_WIFI_STA_START:
        ESP_LOGI(TAG, "STA Started");
        if (WiFi.getMode() == WIFI_MODE_APSTA) {
            ledWiFi = WIFI_LED_STATE::STATE_WIFI_AP;
        } else {
            ledWiFi = WIFI_LED_STATE::STATE_WIFI_CONNECTING;
        }
        break;
    case ARDUINO_EVENT_WIFI_STA_CONNECTED:
        ESP_LOGI(TAG, "STA Connected");
        ledWiFi = WIFI_LED_STATE::STATE_WIFI_CONNECTED;
        break;
    case ARDUINO_EVENT_WIFI_STA_GOT_IP6:
        ESP_LOGI(TAG, "STA IPv6: ");
        // ESP_LOGI( TAG, "%s", WiFi.localIPv6().toString());
        break;
    case ARDUINO_EVENT_WIFI_STA_GOT_IP:
        // ESP_LOGI( TAG, "STA IPv4: ");
        ESP_LOGI(TAG, "%s", WiFi.localIP().toString().c_str());
        break;
    case ARDUINO_EVENT_WIFI_STA_DISCONNECTED:
    case ARDUINO_EVENT_WIFI_STA_LOST_IP:
        ESP_LOGI(TAG, "STA Disconnected -> reconnect");
        WiFi.reconnect();
        ledWiFi = WIFI_LED_STATE::STATE_WIFI_DISCONNECTED;
        break;
    case ARDUINO_EVENT_WIFI_STA_STOP:
        ESP_LOGI(TAG, "STA Stopped");
        break;
    default:
        break;
    }
    ESP_LOGI(TAG, "WiFi mode %d", WiFi.getMode());
}
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

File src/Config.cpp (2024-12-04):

#include "Config.h"
#include <ArduinoSort.h>

namespace AlarmClock {
Config::Config() { }

bool Config::LoadFromPath(fs::FS& fs, const String& path)
{
    File configFile = fs.open(path, FILE_READ, false);
    String json = configFile.readString();
    configFile.close();
    Serial.println(json);
    JsonDocument doc;
    DeserializationError error = deserializeJson(doc, json);
    if (error) {
        Serial.println("----- parseObject() for config.json failed -----");
        Serial.println(error.c_str());
        return false;
    }

    return Load(doc);
}

bool Config::Load(JsonDocument& doc)
{

    // load general settings
    auto general = doc["general"];

    if (general.containsKey("audio_volume")) {
        global.audio_volume = general["audio_volume"].as<float>();
    }

    if (general.containsKey("tz")) {
        global.tz = general["tz"].as<String>();
    }

    // load network settings
    auto network = doc["network"];
    if (network.containsKey("hostname")) {
        global.hostname = network["hostname"].as<String>();
    } else {
        // set default hostname
        char hostname[20];
        uint64_t chipid = ESP.getEfuseMac();
        sprintf(hostname, "esp32-%04X%08X", (uint16_t)(chipid >> 32), (uint32_t)chipid);
        global.hostname = String(hostname);
    }
    if (network.containsKey("static_ip_enabled")) {
        global.isStaticIPEnabled = network["static_ip_enabled"].as<bool>();
    }
    if (network.containsKey("static_ip")) {
        global.local.fromString(network["static_ip"].as<String>());
    }
    if (network.containsKey("subnet")) {
        global.subnet.fromString(network["subnet"].as<String>());
    }
    if (network.containsKey("gateway")) {
        global.gateway.fromString(network["gateway"].as<String>());
    }
    if (network.containsKey("primary_dns")) {
        global.primaryDNS.fromString(network["primary_dns"].as<String>());
    }
    if (network.containsKey("secondary_dns")) {
        global.secondaryDNS.fromString(network["secondary_dns"].as<String>());
    }

    // load alarm settings
    JsonArray alarmsJSON = doc["alarms"];
    size_t i = 0;
    alarms.clear();
    alarmTimes.clear();
    for (auto a : alarmsJSON) {
        if (i == MAX_ALARMS) {
            Serial.println("Maximum number of alarms reached!");
            break;
        }
        // read music type first
        String music_name = a["music"];
        String music_url = a["file"];
        auto music_type = AlarmClock::MusicStream::stringToType(a["type"]);
        auto stream = AlarmClock::MusicStream(music_name, music_url, music_type);

        // alarm params
        String name = a["name"];
        String file = a["file"];
        int hour = (int)a["hour"];
        int minute = (int)a["minute"];
        DaysOfWeek dow;
        for (const auto& d : a["dow"].as<JsonArray>()) {
            int day = (int)d;
            dow.push_back(d.as<int>());
        }
        bool enabled = a["enabled"].as<bool>();
        float volume = a["volume"] | 0.11;
        volume = min(1.f, max(volume, 0.f));

        // push to list
        AlarmClock::Alarm alarm(name, dow, hour, minute, stream, enabled, volume);
        alarms.push_back(alarm);
        Serial.printf("Alarm %s\n", alarm.toString().c_str());
        if (alarm.isEnabled()) {
            for (const auto& day : alarm.getDow()) {
                if (alarmTimes.full()) {
                    Serial.println("Maximum number of alarm times reached!");
                    break;
                }
                alarmTimes.push_back(AlarmTime(alarm, day));
            }
        }
    }

    return true;
}

void Config::Save(fs::FS& fs, const String& path)
{
    JsonDocument doc;
    serializeJsonPretty(doc, Serial);
    Save(doc);
    serializeJsonPretty(doc, Serial);
    writeJSONFile(fs, path, doc);
}

void Config::Save(JsonDocument& doc)
{
    // save alarms
    auto alarmsJSON = doc["alarms"].to<JsonArray>();
    for (auto& alarm : alarms) {
        auto alarmJSON = alarmsJSON.add<JsonObject>();
        alarm.toJSON(alarmJSON);
    }

    // save general settings
    auto generalJSON = doc["general"].to<JsonObject>();
    generalJSON["audio_volume"] = global.audio_volume;
    generalJSON["tz"] = global.tz;

    // save network settings
    auto networkJSON = doc["network"].to<JsonObject>();
    networkJSON["hostname"] = global.hostname;
    networkJSON["static_ip_enabled"] = global.isStaticIPEnabled;
    networkJSON["static_ip"] = global.local;
    networkJSON["subnet"] = global.subnet;
    networkJSON["gateway"] = global.gateway;
    networkJSON["primary_dns"] = global.primaryDNS;
    networkJSON["secondary_dns"] = global.secondaryDNS;
}

GlobalSettings& Config::GetGlobalConfig() { return global; }

Array<AlarmTime, MAX_ALARMS>& Config::getAalarmTimes() { return alarmTimes; }

AlarmTime& Config::GetNextAlarmTime() { return alarmTimes[alarmNext]; }

void Config::SortAlarmTimes()
{
    // sort alarms by date
    sortArray(alarmTimes.data(), alarmTimes.size());
}

void Config::SelectNextAlarmTime(tm& timeinfo)
{
    bool selected = false;
    for (size_t i = 0; i < alarmTimes.size(); i++) {
        if (alarmTimes[i] > timeinfo) {
            alarmNext = i;
            selected = true;
            break;
        }
    }

    // if no alarm time is bigger, alarm is the first one in the new week
    if (!selected) {
        alarmNext = 0;
    }
}

void Config::IncrementNextAlarmTime() { alarmNext = (alarmNext + 1) % alarmTimes.size(); }

String Config::GetPOSIXTimezone()
{
    auto idx = global.tz.indexOf("|");
    return global.tz.substring(idx + 1);
}
}

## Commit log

2020-09-06 Changed pins for final board, cleanup, get board infos via http
2020-09-13 Added 7 segment display and simple pcb
    [mp3alarm_pcb.fzz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]
2020-09-27 small changes
    [mp3alarm_pcb.fzz, pcb.fzz]
2020-10-27 bugfixes, added language support, timezone/dst
    [main.cpp]
2020-11-19 - Added FM radio - refactoring: moved streaming etc. to MusicStream - ToDo: I2S Radio input lib not working yet
    [main.cpp]
2020-11-19 Added FM stuff / bugfixes
    [main.cpp]
2020-12-22 KiCAD PCB Webinterface bugfixes
    [mp3alarm-B_Cu.gbr, mp3alarm-B_Mask.gbr, mp3alarm-B_Paste.gbr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]
2021-01-11 Updated PCB (added QR code, OSHW logo, etc) Some bugfixes for webinterface Updated README
    [mp3alarm-B_Cu.gbr, mp3alarm-B_Mask.gbr, mp3alarm-B_Paste.gbr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]
2023-01-08 New PCB with RDA5807FP
    [mp3alarm-B_Cu.gbr, mp3alarm-B_Mask.gbr, mp3alarm-B_Paste.gbr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]
2023-01-31 * New partition table * Changed to audio pipeline (arduino-audio-tools) * PCB: new sat connector layout * PCB: added pullup resistors for switch pins
    [mp3alarm.kicad_pcb, mp3alarm.kicad_sch, partitions.csv]
2023-05-10 * Added new options for static network settings * Improved firmware update via HTTP (update firmware and filesystem) * several bugfixes
    [AudioProvider.cpp, main.cpp]
2023-05-16 PCB updates
    [mp3alarm-B_Cu.gbr, mp3alarm-B_Mask.gbr, mp3alarm-B_Paste.gbr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]
2023-05-22 Fixed deleting files via webcontrol
    [main.cpp]
2023-06-06 * Fixed file playback for alarm * Fixed alarm volume scale at webcontrol
    [main.cpp]
2023-07-26 * Playback volume bugfix * Added hardware button to stop playback * small bugfixes
    [AudioProvider.cpp, main.cpp]
2023-11-14 Ported project to ESP32S3 with SD_MMC support and pinned AsyncTCP task to core0 to prevent stuttering
    [main.cpp]
2023-12-08 Several bugfixes and reactoring: * If there is no config on startup, a default config.json, streams.json and songs directory will be created * Fixed bugs for file upload * Webinterface shows file siz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
    [AudioProvider.cpp, Config.cpp, main.cpp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]
2023-12-08 * Removed unnecessary delay on start * Forced AP mode deletes WiFi config so it stays in AP mode * Broken alarms fixed * File upload returns the right file size instead 0
    [main.cpp]
2023-12-08 * Latest PCB update for ESP32S3
    [mp3alarm-B_Cu.gbr, mp3alarm-B_Mask.gbr, mp3alarm-B_Paste.gbr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]
2023-12-09 Updated to latest PCB
    [Amphenol RF 172363.STEP, TRS Jack PJ-313.stp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]
2023-12-26 Changed WiFi/System LED status handling Removed Caching for static files
2024-01-11 * Updated audio pipeline libs * Webinterface: load songs first, then config to prevent not found songs in config * prevent JSON parsing errors for some webstream URLs * Increased buffer size for bett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
    [AudioProvider.cpp, main.cpp]
2024-01-11 * Yellow status LED if time cannot be synced * Fixed bug that selected a wrong following alarm
    [main.cpp]
2024-03-11 Updated PCB
    [mp3alarm-B_Cu.gbr, mp3alarm-B_Mask.gbr, mp3alarm-B_Paste.gbr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]
2024-04-16 * Updated ArduinoJSON code * TM1637Display shows more errors
    [Config.cpp, main.cpp, utils.cpp]
2024-04-20 Pin ArduinoJSON version to 7.0.4
2024-04-20 Latest PCB update
    [mp3alarm-B_Cu.gbr, mp3alarm-B_Mask.gbr, mp3alarm-B_Paste.gbr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]
2025-11-04 Updated libs and memory layout for ESP32-S3 N16-R2
    [large_littlefs_16MB.csv]
2025-11-21 New partition layout
    [large_fat_16MB.csv]
2025-12-10 Fix error message on file upload due to wrong http response
    [main.cpp]
2025-12-10 Fix for not starting config portal
    [main.cpp]
2025-12-11 Use current volume when playing audio instead of general volume setting
